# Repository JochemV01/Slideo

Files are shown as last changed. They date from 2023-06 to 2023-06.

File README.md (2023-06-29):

# Slideo
Welcome to this repository with the supplamentory materials of my final bachelor project. On this repo, you can find any relevant files you might need to reproduce the project or perform a follow-up.

## Contents
- CAD model
  - STL files which can be 3D printed
  - SolidWorks files which can be edited
- "Demoday" files
  (Demoday is the moment the project is presented to the public)
  - Arduino code (for demonstration purposes, a button activates the vibration patterns)
  - Electronics circuit which works with code
  - Poster (showcased on stand)
  - Video (showcased on stand and used in pitch)
- Questionnaire files
  - The full questionnaire with all questions
  - The responses to the questionnaire in Excel
- User test files
  - The video used
  - Arduino code (the haptic feedback synchronized with the video)
  - Electronics circuit which works with code
  - Results in Excel
- The design brief (initial goals and setting)
- An overview of the design sprint (brainstorming)
- The final report

## Contact
If you have any questions for me, feel free to reach out! You can reach me at j.r.p.verstegen@student.tue.nl.

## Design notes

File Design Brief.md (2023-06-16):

*Jochem Verstegen - 1561170 - FBP - Subject: AV Interaction*
# Design Brief
## Setting
There will be a transition period in which automated vehicles (AVs) will become more advanced and more common. A large part of this transition will consist of mixed traffic, which is a situation where humans manually driving a vehicle will share the roads with AVs. At first, AVs will not be fully automated yet, starting with level 3. But at some point, AVs can advance into fully automated vehicles capable of driving safely in any circumstances humans would be able to drive in. As AVs become increasingly more widespread, the opportunity to create an intelligent transport system (ITS) of sorts emerges, as this will lead to bigger advantages like increased safety, efficiency, sustainability and comfort (Ahangar et al., 2021).

This opportunity has already been identified by the EU, as is evident from their project called "[AutoNet2030](https://cordis.europa.eu/project/id/610542)", from 2013 to 2016. This project involved, amongst others, a definition of a network of AVs. As described by de La Fortelle et al. (2014): vehicles with a cooperative mode are either manually driven by a human while guided by the cooperation (*cooperative vehicle*), or support automated driving (*cooperative automated vehicle*). Cooperation should happen in local and global cooperative areas, where the local areas are meant for sharing manoeuvring information and the global areas are for communicating information like weather conditions or construction on a larger geographical area. Local cooperative areas can be either static or dynamic, the static area resides in infrastructure at strategic places like highway entrances or intersections, the dynamic area moves with a group of vehicles in short vicinity sharing similar traffic objectives. The goal of AutoNet is to allow cooperative vehicles to seamlessly create and join areas based on their positions relative to each other and infrastructure, it is a type of vehicle-to-everything (V2X) communication.

## Idea
My idea is to design a device, preferably physical with haptic interaction, which can be used on a bicycle. This device allows its user to become a part of the AutoNet network as described above, to understand it and interact in it. It can be used to actively participate in negotiations with other cooperative vehicles, mainly automated ones.

I will be focusing on a person driving a city bike, used as a means of personal transit from one location to another, on a route on which they are familiar. Using the device, the driver can indicate their plans, like what moves they are planning to make. The device will communicate this information with the network, in order to give the user feedback about whether its safe to make the move. This allows the user to take part in the complex communication within the system, and negotiate with it. A reason for aiming for haptic interaction is that it can be used with touch, decreasing the need to visually interact with the device. This way, the user does not have to shift their visual attention to the device and can continue monitoring their environment for safety. Additionally, it is a possibility to include multimodality in the design.

To have a clear goal for the design, it is important to determine a specific situation in which the design will be situated. This will be a major street with a speed limit of 50km/h, with a residential minor street on either side with a speed limit of 30km/h. The major street has painted bike lanes on either side, so cyclists are always on the right side of the street. The cyclist will be approaching these minor streets from the major street and wants to turn left into the left minor street. This would require crossing the street in order to complete the turn. The cyclist will use the device to indicate they are planning to make a left turn, using the feedback to determine if they can go or have to wait.

Some questions to be answered are:
- If the turn is not possible at the moment, how can this be made clear to the user?
- Is a system to communicate a human's intent desirable, or is it preferred to exclusively use eHMIs on other vehicles to tell the human where they can go?
	- Would people appreciate the extra control this gives them?
	- Would this change the amount of information to take into account when making a decision?
	- How would it affect trust levels?
- Would this only be helpful near the end of the transition period, or also earlier when AVs are not as common yet?
	- In case of a cooperative vehicle, which as described in AutoNet is not driving automatically, is communication more likely to happen through the network or from human to human?

Note that this device is not meant to replace eHMIs, but to coexist alongside it. Where eHMIs would be used to monitor the environment, this would be used to negotiate with the system.

## References
Ahangar, M. N., Ahmed, Q. Z., Khan, F. A., & Hafeez, M. (2021). A Survey of Autonomous Vehicles: Enabling Communication Technologies and Challenges. _Sensors_, _21_(3), Article 3. [https://doi.org/10.3390/s21030706](https://doi.org/10.3390/s21030706)

de La Fortelle, A., Qian, X., Diemer, S., Grégoire, J., Moutarde, F., Bonnabel, S., Marjovi, A., Martinoli, A., Llatser, I., Festag, A., & Sjöberg, K. (2014, September 8). _Network of automated vehicles: The AutoNet 2030 vision_. ITS World Congress. [https://hal-mines-paristech.archives-ouvertes.fr/hal-01063484](https://hal-mines-paristech.archives-ouvertes.fr/hal-01063484)

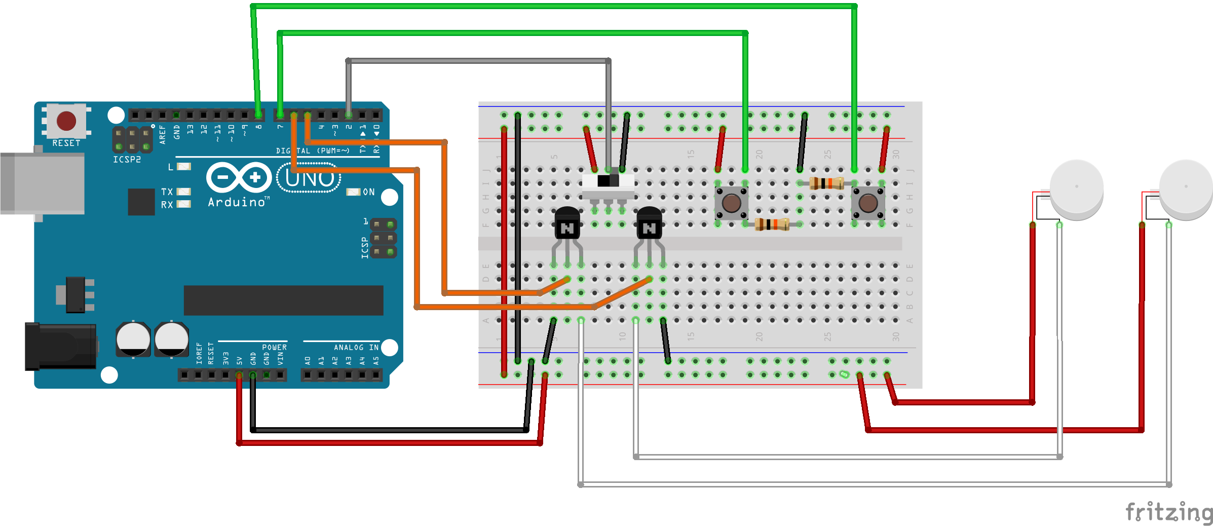
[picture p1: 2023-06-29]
Demoday/Electronics.png

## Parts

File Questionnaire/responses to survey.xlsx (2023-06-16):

ID | Starttime | Endtime | Language | Consent | first-thoughts-cyling-amongst-avs | cycling-experience | rate-current-infra | describe-current-infra | cycle-when-growing-up | rate-growup-infra | describe-growup-infra | sh-intuitive | sh-feel-safer | sh-trust-register-communicate | sh-feedback-behavior | sh-would-use | sh-like | sh-improve | sh-comments | rp-intuitive | rp-feel-safer | rp-trust-register-communicate | rp-feedback-behavior | rp-would-use | rp-like | rp-improve | rp-comments | ts-intuitive | ts-feel-safer | ts-trust-register-communicate | ts-feedback-behavior | ts-would-use | ts-like | ts-improve | ts-comments | kr-intuitive | kr-feel-safer | kr-trust-register-communicate | kr-feedback-behavior | kr-would-use | kr-like | kr-improve | kr-comments | compare-easiest-to-trigger | compare-likely-misfire | compare-best-feedback-reaction-avs | compare-right-amount-safety | compare-most-likely-use | compare-least-likely-use | age | reasons-to-cycle | statement-technology | toughts-cycling-with-concept
6 | 2023-03-24 10:57 | 2023-03-24 11:34 | en | yes | It's hard to envision how these cars will behave. If it is not consistent, I would constantly be watching the behaviour of these cars and trying to anticipate. However, humans are also not consistent, and to that I always anticipate by slowing down and watching for visual ques. | regularly | 8 | very good | yes different location | 6 | mediocre | 4 | 4 | 3 | 5 | 2 | Good reachability | / | / | 1 | 3 | 2 | 5 | 3 | Feels seamless | / | I move around a lot on my bike, I would be scared about accidentally triggering it | 1 | 2 | 5 | 2 | 1 | / | / | I would find this a really awkward interaction | 1 | 3 | 5 | 3 | 3 | / | / | I would find it disrupting for my knee placement whilst biking | sh; | sh;ts; | sh; | sh; | sh; | sh; | 25 | Traveling to work / school;Recreational;As a sport; | tech-useful-use-regularly
7 | 2023-03-24 11:29 | 2023-03-24 11:35 | en | yes | Bike can have eHMIs | regularly | 10 | very good | yes different location | 1 | pretty bad | 5 | 4 | 5 | 5 | 4 | No physical movement |  |  | 1 | 2 | 2 | 1 | 2 | Not practically feasible |  |  | 3 | 3 | 3 | 3 | 3 |  |  | Twisting seat is challenging when doing speed biking | 2 | 1 | 2 | 4 | 1 |  |  | It restricts my knee movements | sh; | rp; | sh; | sh; | sh; | rp; | 25 | Traveling to work / school;Recreational; | like-tech-enjoy-new
8 | 2023-03-25 12:15 | 2023-03-25 12:24 | en | yes |  | regularly | 10 | very good | yes same location |  |  | 2 | 4 | 3 | 4 | 4 |  |  | I would be scared to lose my balance when accidentally sliding the handle | 4 | 4 | 4 | 3 | 4 |  |  |  | 1 | 2 | 3 | 3 | 2 |  |  | I would again be scared to lose balance, and I don't know if I'm mobile enough to do this at every turn | 1 | 2 | 3 | 3 | 1 |  |  | I think it would be difficult to time this when cycling fast, which may result in hurting your knee | rp; | sh; | sh; | rp; | rp; | ts;kr;sh; | 20 | Traveling to work / school;Recreational; | like-tech-enjoy-new
9 | 2023-03-25 13:23 | 2023-03-25 13:47 | en | yes | As someone who commutes via bicycle, I feel that automated vehicles would lead to increased uncertainty. A lot of cyclists look to the drivers to see if they have been noticed, so something with the automated vehicles may have to replace this. Of course, a world of level 4 and 5 vehicle automation would be a very different one to that of ours today. | regularly | 9 | very good | no |  |  | 5 | 3 | 3 | 4 | 3 | I like that the interaction is simple to understand and straightforward. |  | I feel that the motion of sliding would decrease my trust in the handlebars, as I would be concerned about the risks of the handlebars moving when I expect them to be fixed. | 5 | 4 | 4 | 3 | 5 | I like that rp would not interfere with the normal operation of the bicycle, and that my hands would stay stationary. | perhaps some way to make sure the pedals can interface well with the user's shoes; not that friction is too low and the pedal rotates under their foot without it being clearly noticeable. |  | 5 | 2 | 2 | 4 | 2 | its operation would be simple and straightforward |  | I think that twisting the body while cycling could be potentially risky; like the handlebars, the seat is a contact point of the bicycle that riders rely on to be fixed. Rotating the body could potentially upset the user's balance- especially in situations where they want to signal a turn, expecting the seat to move, but it unexpectedly doesn't due to an unsafe situation. | 5 | 4 | 2 | 4 | 3 | I like that the idea is really unique and has a lot of potential. | I would be concerned about the system's ability to register my inputs reliably. Maybe some kind of haptic feedback could be implemented to show the user that they have activated the signal. The other major concern would be safety, like making sure the user doesn't get impaled in a crash, or that bailing in a crash (jumping off the bike) is not impeded. |  | kr;rp; | rp;ts; | kr; | kr;rp; | rp;kr; | sh;ts; | 23 | Traveling to work / school; | like-tech-enjoy-new
10 | 2023-03-25 13:24 | 2023-03-25 14:24 | en | yes | these vehicles have to see me and to be able to anticipate on me. For the rest it seems not any different from non-automated vehicles. | regularly | 8 | pretty good | yes same location |  |  | 1 | 1 | 3 | 2 | 1 | It is close to the hands on the handle bar and therefore ready to use | I would make it no sliding. Sliding means you have to pull, which causes you making a turn. Pulling with one hand also gets you out of balance, while balance is mandatory on a bike. | In the Netherlands only there are a lot of different handle bars, regular bikes, mountain bikes, racing bikes, "omafietsen" etc. The racing bike has a bar with various hand positions. where do you pull and how fast can you safely move your hands. | 4 | 4 | 1 | 1 | 4 | it is easy to use. When you want to make a turn you usually don't use the power of your feet so you can easily give signals. | only give feedback when the pedals are not powered because it maygive injuries | the signals need to transfer from the sensor to the computer. this needs to be done by a sliding connection because of the rotating pedal (near the foot). The pedal is near the road, and dirt and sand can easily cause wear to the connection, resulting in bad signals. | 4 | 2 | 2 | 5 | 2 | easy to do | make it vibrating | feedback may get you out of balance on the bike which can be dangerous | 4 | 1 | 5 | 5 | 1 | they are clear and present on your bike | Make sure they can be used at every pedal position | Unsafe during an emergency stop and they restrict the freedom of the legs and knees. | rp; | ts; | sh; | rp; | rp; | kr; | 47 | As a sport;shopping; | like-tech-enjoy-new | all these solutions reduce my biking skills and make me feel less confident on the bike. I would rather trust my own judging ability. Perhaps automated cars can learn body language of cylists.
11 | 2023-03-25 17:00 | 2023-03-25 17:08 | en | yes | I felt a bit scared to make a turn because I didnt dare to hold out my arms :( | regularly | 9 | pretty good | no |  |  | 2 | 3 | 2 | 2 | 1 |  |  |  | 4 | 4 | 3 | 4 | 3 | I think it is pretty innovative |  |  | 4 | 3 | 4 | 4 | 2 |  | I think it could be quite uncomfortable to use |  | 5 | 5 | 4 | 4 | 4 | It create a sense of security because it holds tight on my legs |  |  | kr; | ts; | kr; | kr; | kr; | ts; | 21 | Traveling to work / school; | tech-useful-use-regularly
12 | 2023-03-28 06:58 | 2023-03-28 07:08 | nl | yes | Nee nooit over nagedacht maar lijkt mij nest wel een oplossing voor diverse problemen | regularly | 8 | pretty good | yes same location |  |  | 4 | 4 | 4 | 4 | 4 | Dat je meer duidelijk kunt maken waar je na toe wilt gaan met beide handen aan het stuur | Geen idee |  | 3 | 2 | 2 | 2 | 2 | Lijkt mij niet zo veilig |  |  | 2 | 2 | 2 | 2 | 2 | Lijkt mij niet zo veilig |  |  | 2 | 2 | 2 | 2 | 2 | Lijkt mij niet zo veilig |  |  | sh; | rp;ts;kr; | sh; | sh; | sh; | kr;rp;ts; | 60 | Traveling to work / school; | tech-useful-use-regularly
13 | 2023-03-29 20:21 | 2023-03-29 20:29 | nl | yes |  | occasionally | 8 | very good | yes different location | 9 | very good | 1 | 1 | 1 | 1 | 3 |  |  |  | 1 | 1 | 2 | 1 | 1 |  |  |  | 1 | 1 | 2 | 1 | 1 |  |  |  | 1 | 1 | 1 | 2 | 2 |  |  |  | sh; | ts;rp;kr; | kr;sh; | sh; | sh; | ts;kr; | 37 | Traveling to work / school; | like-tech-enjoy-new | Ik zie het niet snel gebeuren
14 | 2023-03-29 22:00 | 2023-03-29 22:36 | nl | yes | Ik heb hier nog nooit over nagedacht, dus op dit moment heb ik nog geen gedachte hierover. | regularly | 7 | pretty good | yes same location |  |  | 3 | 3 | 2 | 3 | 4 | Je kan je handen aan het stuur houden. Dat is veiliger. | Geen idee, ik zou ze eerst moeten uitproberen om verbeteringen te kunnen aanbrengen. | Het uitschuiven voelt misschien beetje onnatuurlijk. | 4 | 4 | 3 | 3 | 4 | Je hoeft niet aan het stuur te trekken, wellicht veiliger en voelt vertrouwder | Pedalen misschien van kleur laten veranderen | Ik vraag me af of je nog prettig kan trappen met uitgebouwde pedalen | 4 | 3 | 3 | 2 | 4 | Dit lijkt me een kleine moeite om te doen. | Een soort van klik systeem aanbrengen, hoorbaar, zodat je hoort dat je voldoende gedraaid bent | Geen idee | 2 | 2 | 2 | 3 | 3 | Tja, hier heb ik beetje mijn twijfels over. Achteraf monteren is wellicht prettig en een goedkopere oplossing. | Iets erop verzinnen dat ze niet in de weg gaan zitten met het stallen van je fiets. | Mij lijkt het terug duwen van de staaf na de bocht niet zo prettig. | ts; | kr; | ts;sh;rp; | ts;rp; | ts;rp; | kr; | 52 | Traveling to work / school;Recreational; | like-tech-enjoy-new | Het lijkt me een hele uitdaging, zeker met meerdere zelfrijdende auto's om je heen.. Want hoe weet je dan dat alle zelfrijdende auto's jouw bedoeling gezien hebben?
15 | 2023-03-29 22:33 | 2023-03-29 22:43 | en | yes | We’re not there yet | regularly | 8 | very good | yes different location | 9 | very good | 1 | 1 | 1 | 1 | 1 | Don’t don’t don’t. Only useful if more than 99% use it. Including walking pedestrians, pets, etc. | Don’t. Solve the problem at the car end. | Don’t. | 1 | 1 | 1 | 1 | 1 | Don’t | Not use them | Don’t | 1 | 1 | 1 | 1 | 1 | Removal options | Don’t use them. If so, 100% reliability without ever changing batteries | Don’t | 1 | 1 | 1 | 1 | 1 | .. | Remove them | Horrible idea | sh; | ts; | sh;kr;ts; | sh; | sh; | sh; | 20 | Recreational; | like-tech-enjoy-new | I trust it about as well as I trust humans. Not enough to stake my life on them. I drive a smart car anyway and don’t mind looking away for a while. On the freeway
16 | 2023-03-30 09:14 | 2023-03-30 09:23 | nl | yes | Nederland is een fietsland. Ik ben benieuwd hoe een zelfrijdende auto al die fietsers in de gaten zou kunnen houden. | regularly | 6 | mediocre | yes different location | 6 | pretty good | 2 | 2 | 1 | 1 | 2 |  |  | Lijkt me, zeker voor oudere mensen die wat minder stabiel op een fiets zitten, niet veilig | 1 | 1 | 1 | 1 | 1 |  |  | Zeker niet veilig voor oudere fietsers op elektrische fietsen, bovendien moet je er maar net aan denken tijdens het fietsen | 1 | 1 | 1 | 1 | 1 |  |  | Ik vind dit persoonlijk een belachelijk idee. | 1 | 1 | 1 | 1 | 1 |  |  | Onzinnig idee, hoe verzin je het | ts; | kr; | sh; | ts; | sh; | ts;rp;kr; | 65 | Traveling to work / school;Recreational;Bezoek aan vrienden, boodschappen doen; | dont-mind-when-needed | Het lijkt mee helemaal niet veilig voor fietsers. Ze zijn toch al een kwetsbare groep weggebruikers, zelfrijdende auto’s vergroot die kwetsbaarheid alleen maar
17 | 2023-03-30 09:27 | 2023-03-30 09:38 | nl | yes | Eigenlijk nog geen gedachtes | regularly | 7 | pretty good | yes different location | 8 | very good | 3 | 2 | 2 | 2 | 3 | Ik kan me hier nog onvoldoende bij voorstellen | geen idee |  | 3 | 3 | 3 | 3 | 3 | Weet ik nog niet |  |  | 1 | 2 | 1 | 1 | 1 | niks |  | Als ik fiets ga ik wel eens verzitten omdat alsmaar dezelfde houding onprettig is. Dan zou ik met dit hulpmiddel regelmatig een verkeerd signaal afgeven aan achterliggers omdat ik mijn heupen dan even draai | 2 | 1 | 2 | 3 | 2 |  |  | Hoe gaat dit met opstappen? Ik heb een damesfiets met lage instap, en kan zeker niet mijn been over iets heen zwiepen. Ik zie dit echt niet voor me. | rp; | ts; | kr; | rp; | rp; | kr; | 52 | Traveling to work / school;boodschappen doen; | tech-useful-use-regularly
18 | 2023-03-30 09:34 | 2023-03-30 09:40 | nl | yes | Zal even wennen zijn, maar statistisch waarschijnlijk wel veiliger | rarely | 8 | very good | yes same location |  |  | 3 | 4 | 5 | 4 | 4 | Makkelijk te integreren | Zorgen dat ze zeker niet gaan schuiven als je over een hobbeltje gaat |  | 1 | 1 | 2 | 2 | 1 | Weinig | Niet aan beginnen, probeer maar eens met gedraaide voet een rondje te trappen als je niet hele sterke kruisbanden hebt |  | 3 | 2 | 2 | 3 | 3 | Makkelijk te bedienen | Zorgen dat het geen false positives geeft |  | 3 | 2 | 3 | 3 | 3 | Makkelijk te gebruiken | Geen idee |  | sh; | rp;ts; | sh;kr; | sh;kr; | sh; | rp;ts; | 30 | Recreational;Traveling to work / school; | tech-useful-use-regularly
19 | 2023-03-30 09:48 | 2023-03-30 09:57 | nl | yes | Ik fiets veel en vaak in Rotterdam en het grootste gevaar zijn niet auto's maar de overige fietsers/bromfietsers die denken dat de weg van hun is en ook vooral de voetgangers die met een telefoon aan hun oor of in hun hand totaal niet meer opletten als ze oversteken. | regularly | 9 | very good | yes different location | 8 | pretty good | 2 | 1 | 1 | 5 | 3 | Net veel | Geen idee |  | 1 | 1 | 1 | 1 | 1 |  |  |  | 1 | 1 | 1 | 1 | 1 |  |  |  | 1 | 1 | 1 | 1 | 1 |  |  |  | rp; | ts;kr;sh; | rp; | rp; | rp; | ts;sh;kr; | 61 | Traveling to work / school;Recreational; | like-tech-enjoy-new | Ik vertrouw het meest op mezelf. Daarna auto's met een bestuurder erin en past als laatste een zelf rijdende auto. En daarbij hoe kan ik een zelf rijdende auto (of een auto met bestuurder die zelf rijdt) herkennen. Nogmaals ik vertrouw mezelf het meest. En over de enquete: voeg ook een optie toe : geen van de 4 want nu moest ik een antwoord geven wat ik eigenlijk niet wilde.
20 | 2023-03-30 09:25 | 2023-03-30 10:06 | nl | yes | Je kan als fietser ook niet zien of een zelfrijdende auto jou wel heeft gezien. Bij een bestuurder kan je dat wel zien. Waarom zou je de problematiek dat een zelfrijdende auto een fietser niet goed kan inschatten verschuiven naar de fietser? Het lijkt mij dat een zelfrijdende auto zich moet aanpassen aan de andere verkeersdeelnemers en niet dat de andere verkeersdeelnemers zich moeten aanpassen aan zelfrijdende auto's. | regularly | 8 | pretty good | yes different location | 5 | pretty bad | 1 | 1 | 1 | 4 | 2 |  |  | Ik begrijp niet goed hoe je kan voorkomen dat er een bedoeling wordt geregistreerd zonder dat jij het wil (omdat je per ongeluk iets verschuift.). Hoe weet de fiets dat je de bocht volledig hebt afgerond en nu weer rechtdoor gaat fietsen? | 1 | 1 | 1 | 4 | 1 |  |  | Ik begrijp niet goed hoe je kan voorkomen dat er een bedoeling wordt geregistreerd zonder dat jij het wil (omdat je per ongeluk iets verdraait.). Hoe goed blijft dit draaien als de trappers onder de modder zitten? Hoe weet de fiets dat je de bocht volledig hebt afgerond en nu weer rechtdoor gaat fietsen? | 1 | 1 | 1 | 4 | 2 |  |  | Ik begrijp niet goed hoe je kan voorkomen dat er een bedoeling wordt geregistreerd zonder dat jij het wil (omdat je per ongeluk iets verdraait.). Hoe weet de fiets dat je de bocht volledig hebt afgerond en nu weer rechtdoor gaat fietsen? | 1 | 1 | 1 | 4 | 1 |  |  | Het ziet eruit alsof je tijdens het fietsen continu staven tegen je knieën krijgt. Lijkt me ook lastig voor fietsen zonder stang, waarbij de gebruikers niet gewend zijn dat er staven zitten die hun verhinderen makkelijk op en af te stappen. Hoe weet de fiets dat je de bocht volledig hebt afgerond en nu weer rechtdoor gaat fietsen? | ts;sh;rp; | sh;rp;ts; | sh; | sh; | rp; | kr;sh;ts; | 47 | Recreational;Boodschappen; | like-tech-enjoy-new | Het lijkt mij een slecht idee. Als je al wil dat fietsers afslaan beter kunnen communiceren dan lijkt het logischer dat er met knipperlichten wordt gewerkt. Net zoals op een brommer/scooter, inclusief de manier om het knipperlicht te activeren. Dan kan je "onder water" natuurlijk tegelijkeen ander signaal sturen naar zelfrijdende auto's.
21 | 2023-03-30 10:47 | 2023-03-30 10:55 | nl | yes |  | occasionally | 8 | pretty good | yes different location | 6 | mediocre | 1 | 1 | 2 | 2 | 1 | Niets | Niet laten schuiven | Schuiven zal snel tot een onbedoelde richtingsverandering leiden en is daarmee onveilig. | 2 | 2 | 2 | 3 | 1 | Geen handen nodig, beïnvloedt stuurgedrag niet. | Geen idee | Conflicteert met click-pedalen, die ook al een draaiende beweging gebruiken bij het ontgrendelen. | 1 | 1 | 1 | 1 | 1 | Beïnvloedt de balans op de fiets en daarmee het stuurgedrag. | Niet invoeren. | Lijkt me erg ongemakkelijk. | 2 | 2 | 2 | 2 | 1 | Houdt handen vrij. | Geen idee | Bemoeilijkt op- en afstappen. Onveilig. | rp; | ts;kr; | rp; | rp; | rp; | ts;sh; | 53 | Recreational;As a sport; | tech-useful-use-regularly
22 | 2023-03-30 10:39 | 2023-03-30 10:55 | nl | yes | Ik ga ervan uit dat zodra dit de realiteit is, er voldoende onderzoek is gedaan om er zeker van te zijn dat het veilig kan. Misschien is het tegen die tijd wel veiliger dan wanneer er een onvoorspelbare automobilist rijdt. | regularly | 8 | very good | yes same location |  |  | 3 | 4 | 3 | 4 | 4 |  | Ik zou misschien iets willen dat wat meer opvalt, zodat andere fietsers ook beter zien wat ik ga doen. |  | 4 | 4 | 3 | 3 | 4 | Makkelijk te gebruiken met handen aan het stuur | Ik weet niet of je de feedback van de pedalen (bv trillingen) goed kunt waarnemen op slechte/hobbelige wegen bijvoorbeeld. |  | 2 | 3 | 3 | 3 | 3 |  | Ik denk dat het moeilijker te gebruiken is dan de andere opties, met name voor ouderen. |  | 3 | 4 | 4 | 4 | 4 | Zijn wat groter en degelijker om te gebruiken dan de rest denk ik | Is denk ik wel oncomfortabel met op en afstappen |  | sh;kr; | ts;rp; | kr;sh; | kr; | sh;kr; | ts; | 20 | Traveling to work / school;As a sport; | tech-useful-use-regularly
23 | 2023-03-30 10:09 | 2023-03-30 10:58 | nl | yes | Ik zou constant op mijn hoede zijn, omdat ik voorlopig weinig vertrouwen heb in de zelfrijdende technologie. | regularly | 7 | pretty good | yes different location | 7 | pretty good | 1 | 1 | 1 | 1 | 2 | Niets | Slecht idee, verbeteren is zinloos. | Uitschuivende handvatten (let op: met dubbel t!) maken een onnatuurlijke beweging noodzakelijk en geven kans op slingeren. Veel fietsen hebben handvatten die niet min of meer naar links/rechts wijzen, maar naar achteren. | 1 | 1 | 1 | 1 | 1 | Niets | Slecht idee, verbeteren zinloos. | Bezwaren vergelijkbaar met de handvatten. De kans op onbedoeld richting aangeven lijkt me ook nog eens groot, vooral bij fietsen in druk stadsverkeer. | 1 | 1 | 1 | 1 | 1 | Niets. | Het mechanisme vastzetten! | Een draaiend zadel? Echt waar? Heeft u wel eens gefiets met een zadel dat wat kon bewegen? En wat doet dit high-tech zadel als ik bij een kruising links over mijn schouder kijk om te zien of ik veilig rechtdoor kan? | 1 | 1 | 1 | 1 | 1 | Niets | Onmogelijk te verbeteren. | Dit is het meest onpraktische en gevaarlijkste scenario van dit onderzoek, bv bij opstappen, afstappen, voet op de grond (bv bij stoplicht). De kans op (eenzijdige) ongelukjes, valpartijen en slingeren is veel te groot. | kr;ts;rp; | ts;kr;rp; | sh; | sh;rp;ts; | sh; | ts;rp;kr; | 56 | Traveling to work / school;Recreational; | like-tech-enjoy-new | Als zelfrijdende auto's niet goed kunnen reageren op fietsers, is de technologie kennelijk niet goed genoeg. De vier scenario's vind ik ronduit slecht en vergezocht. Het zijn onnatuurlijke "oplossingen" voor andermans problemen. Als "richtingaanwijzer" op een fiets lijkt me een (terugverende) druk- of schuifknop in beide handvatten, onder of naast de duim, nogal voor de hand te liggen en verreweg het handigst te gebruiken. Waarom wordt dat niet meegenomen in het onderzoek? Niet aan gedacht of niet sexy genoeg? Bij de laatste vragen (de keuze voor een scenario) heb ik lukraak wat ingevuld: *geen enkel scenario* wil ik gebruiken of verhoogt mijn veiligheids gevoel.
24 | 2023-03-30 11:27 | 2023-03-30 11:42 | nl | yes | Zoals het "besturen" van een semi-zelfrijdende auto is het een kwestie van vertrouwen in de hulpmiddelen, eerst zweet op het voorhoofd van de spanning later relaxed achteroverleunend | occasionally | 8 | pretty good | yes same location |  |  | 1 | 2 | 2 | 3 | 2 | Ik zie alleen maar nadelen | voorkomen dat er per ongeluk geschoven wordt | te fragile in mijn ogen | 1 | 1 | 1 | 1 | 1 | niets enkel ongemak | niet te verbeteren wederom te snel verkeerd te gebruiken | niets | 1 | 1 | 1 | 1 | 1 | niets | onmogelijk | comfort is helemaal weg op deze manier | 1 | 1 | 1 | 1 | 1 | niets | ?? | levensgevaarlijk | rp;ts; | ts;sh;rp; | kr; | ts; | ts; | kr;ts;sh; | 54 | Traveling to work / school; | like-tech-enjoy-new
25 | 2023-03-30 11:25 | 2023-03-30 11:48 | nl | yes | Erg gevaarlijk. Als er echt zelf rijdende auto's dan stop ik met fietsen | occasionally | 8 | mediocre | no |  |  | 1 | 1 | 1 | 1 | 1 | Dit probleem moet opgelost worden door de bestuurder of eigenaar van die auto, niet door de fietser |  | Een automobilist hoeft zich niets aan te trekken van een of ander verzinsel van iemand. Wat ook niet gaat werken is dat het jullie kennelijk niet bekend is dat de meeste sturen van een fiets niet naar rechts en links uitsteken naar achter, Zoals een stuur van een stadsfiets. En wat denk ja van een vlinderstuur op een wielrennersfiets. Zaterdag is het 1 APRIL. Leuk bedachte grap | 1 | 1 | 1 | 1 | 1 | niets | gaat niet | De voet op de trapper op de tekening staat n helemaal verkeerd. Een trapper zit tegen de kan aan, niet onder de voorvoet | 1 | 1 | 1 | 1 | 1 | het idee alleen al. NEE | vast zetten |  | 1 | 1 | 1 | 1 | 1 | niets | niet invoeren | bestuurders van bestuurder loze autoś uitleggen dat er ook fietsers op de weg rijden, en dat een fietser nu eenmaal geen verplicht fietsrijbewijs heeft | rp; | sh; | rp; | sh; | kr; | kr;sh;ts; | 64 | goedkoper als auto; | not-interested | De bestuurders van bestuurderloze auto's veroorzaken een probleem, dus daar moet het opgelost worden, niet bij de fietser
26 | 2023-03-30 15:34 | 2023-03-30 15:48 | nl | yes |  | regularly | 8 | very good | yes different location | 7 | pretty good | 1 | 1 | 1 | 1 | 1 |  |  | Door het verschuiven van de handvatten verander je ook je rijeigenschap en het "gevoel" met je fiets. | 1 | 1 | 1 | 1 | 1 |  |  | Bij het fietsen op een racefiets op mtb (door de stad) zit je vast aan je pedalen daar door geen mogeijkheid om de hak te kunnen draaien. | 1 | 1 | 1 | 1 | 1 |  |  | Door het gemak van het draaien draai je makkelijk weer terug in de originele positie of zelfs de verkeerde richting op. Vergelijkbaar met een verouderde verende zadelpen die ook makkelijk zijdelings beweegt. | 2 | 3 | 1 | 1 | 1 |  |  | Het gevoel van vrijheid raak je denk ik kwijt door de staven aan je knieën te bevestigen. Hoe om te gaan met extreme O benen of mensen die van zichzelf met "zwenkende" knieën fietsen? | rp;sh; | ts;rp; | kr; | sh; | sh; | ts;kr;rp; | 35 | Traveling to work / school;Recreational;As a sport; | like-tech-enjoy-new
29 | 2023-03-30 16:08 | 2023-03-30 16:18 | en | yes | As I cyclist it shouldn't matter tome whether the vehicles around me are automated or not. | regularly | 9 | very good | yes different location | 6 | mediocre | 1 | 1 | 1 | 1 | 1 | Nothing | Forbid them. | If I have to pull a handle sideways, I can't at the same time indicate my direction change the normal way to every other traffic participant that is not an automated vehicle. | 2 | 3 | 2 | 2 | 2 |  |  |  | 2 | 2 | 3 | 2 | 2 |  |  |  | 2 | 2 | 2 | 2 | 2 |  |  |  | sh; | sh; | sh; | rp; | rp; | sh; | 45 | Traveling to work / school; | like-tech-enjoy-new
30 | 2023-03-30 18:06 | 2023-03-30 18:40 | nl | yes | In eerste instantie lijkt het mij heel gevaarlijk omdat fietsers en dan met name kinderen en ouderen vaak heel onverhoeds bewegingen kunnen maken... | regularly | 7 | pretty good | yes same location |  |  | 1 | 1 | 1 | 1 | 1 |  | Het lijkt mij erg gevaarlijk | Het lijkt mij erg gevaarlijk omdat ik niet kan inschatten wat er gebeurd bij onverwachte bewegingen. Hoe kun je het stuur stevig vasthouden terwijl de handgrepen uittrekbaar zijn. Verder zouden de extra lichten mij extra afleiden van het verkeer. En dat is in strijd met het veilig willen fietsen | 3 | 3 | 3 | 2 | 4 | Je blijft je stuur goed vasthouden |  | Zou dit dan zijn zodat je je hand niet meer uit steekt? Hoe zien andere weggebruikers wat jij gaat doen in het verkeer? Hoe zit het met pedalen met kliksysteem? | 2 | 1 | 2 | 3 | 1 |  |  | Dit lijkt mij persoonlijk ook heel gevaarlijk omdat ik door de draaiende beweging te maken me niet stabiel zou voelen. En dus onveilig. Zal een groot verschil geven of je jong of oud bent, of je lichamelijk gezond bent of niet | 4 | 4 | 4 | 3 | 2 | Je blijft stabieler |  | Deze manier lijkt mij het minst ingrijpende qua fietsen en stabiliteit. Maar vraag me af of dit bruikbaar is wanneer je knieklachten hebt. Verergeren deze dan omdat je een onnatuurlijke beweging moet doen bij het fietsen? | kr; | sh;ts;rp; | rp;kr; | kr; | kr; | ts;sh; | 51 | Recreational; | dont-mind-when-needed | Ik vind eigenlijk alle opties niet toe te passen voor mij, lichamelijk gezien. Ikzelf zou eerder een mogelijkheid uitzoeken zoals een knopje op de linker en rechter stuurhelft om te activeren. Net zoals bv de versnelling te verzetten. Zo blijft mijn aandacht bij het verkeer, en ik blijf stabiel op mijn fiets
31 | 2023-03-31 07:48 | 2023-03-31 07:54 | nl | yes |  | regularly | 8 | very good | yes different location | 8 | very good | 1 | 1 | 1 | 1 | 1 |  |  |  | 1 | 1 | 1 | 1 | 1 |  |  |  | 1 | 1 | 1 | 1 | 1 |  |  |  | 1 | 1 | 1 | 1 | 1 |  |  |  | ts; | sh;rp;ts; | kr; | rp; | rp; | sh;kr;rp; | 60 | Traveling to work / school; | tech-useful-use-regularly
32 | 2023-03-31 09:52 | 2023-03-31 13:18 | nl | yes | Nee, ik heb daar nog nooit over nagedacht. | regularly | 8 | very good | yes different location | 8 | very good | 3 | 4 | 2 | 3 | 4 | Het lijkt me dat je eerder uit balans raakt. | Door inknijpen van het handvat een binnendeel naar buiten schuift en weer terug, minder kans op uit balans raken en uitschuifbare deel kan langer zijn dan alleen een schuifbaar handvat. | Ik ben bang dat het uitschuiven ook kan gebeuren als het niet nodig is, daardoor is de kans dat de fietser uit balans raakt te groot. | 2 | 2 | 2 | 2 | 2 | Als de pedalen een sein geven aan de zelfsturende auto's zal daar vast op gereageerd worden. Het lijkt met voor niet-zelfrijdende auto's, dus met gewoon een chauffeur lastig om zo alles onder controle te houden. | geen idee | Nee, nooit over nagedacht. | 1 | 1 | 2 | 3 | 1 | Ik vind een draaiend zadel helemaal niets! | Vastzetten! | Ik vind een draaiend zadel erg onstabiel. | 3 | 3 | 3 | 3 | 3 | Je hoeft je handen niet te gebruiken. | Ik heb geen idee, maar is er ook nagedacht over een kinderzitje aan het stuur? Ik zie die combinatie niet zo goed voor ogen. Volgens mij past dat niet beide tegelijk op een fiets. | nee | sh; | ts;kr;rp; | sh; | sh; | sh; | kr;ts;rp; | 66 | Recreational;boodschappen doen; | tech-useful-use-regularly | Het geeft me geen veilig gevoel. De mens is wispelturig, kijkt om zich heen, bedenkt op het laatste moment dat er een andere richting gevolgd moet worden. Ik ben bang dat zelfsturende auto's niet op tijd zullen reageren.
33 | 2023-04-11 14:50 | 2023-04-11 14:55 | en | yes |  | occasionally | 8 | very good | yes different location | 6 | pretty good | 1 | 1 | 2 | 2 | 2 |  |  |  | 1 | 1 | 1 | 1 | 1 |  |  |  | 1 | 1 | 1 | 1 | 1 |  |  |  | 1 | 1 | 1 | 1 | 1 |  |  |  | sh; | ts;rp;sh; | sh; | sh; | sh; | kr;ts;rp; | 35 | Recreational; | like-tech-enjoy-new
34 | 2023-04-12 09:06 | 2023-04-12 09:24 | nl | yes | De eerste gedachte is dat ik als fietser niet iets extras moet aanschaffen om veilig in het verkeer te kunnen navigeren. De zelfrijdende auto is dan niet op een hoog genoeg niveau om echt zelfrijdend te zijn. | occasionally | 9 | pretty good | yes different location | 9 | very good | 2 | 2 | 4 | 3 | 2 | De mogelijkheid voor knipperlichten voor overige weggebruikers ( die wel nodig zijn omdat anders voetgangers en fietsers niet weten wat de bedoeling van de fietser is) | ik zou het eerder een knop maken die kan schuiven ipv de handvaten zelf. | het idee van het schuiven van de handvaten geeft een idee van een mogelijke onbalans omdat je een handvat moet schuiven. | 4 | 2 | 3 | 4 | 2 | Concept is simpel, je kan je handen aan het stuur houden. |  |  | 1 | 1 | 4 | 3 | 2 | Het zal een duidelijk makkelijk te interpreteren signaal zijn |  | Als fietser lijkt mij niks ververlender dan een zadel wat kan draaien. Als je kracht wil zetten tijdens het fietsen komt er vaak ook kracht op het zadel waardoor het vaak onbedoeld zal draaien. | 1 | 2 | 4 | 4 | 3 | Duidelijk te interpreteren signaal |  | Ik ben groot en lang, de kniestaven zullen dus makelijk aanpasbaar moeten worden wil je mij bv op die fiets kunnen laten fietsen. Ik pak soms ook wel de fiets van mijn vrouw die 30 cm kleiner is, dus grote aanpasbaarheid nodig. | sh; | kr;ts; | sh;kr; | rp;sh; | sh; | kr;ts; | 44 | Recreational;As a sport; | like-tech-enjoy-new | Van je vier concepten lijkt mij de handvaten het handigst maar dan aangepast als een simpele aangepaste knop ipv het onthandige uitschuiven. Belangrijkste is dat het concept niet alleen de autos in gedachten houd maar ook het communiceren naar andere fietsers, wandelaars en ook bv de stoplichten.
 |  | 0.7
age | sh-intuitive | sh-feel-safer | sh-trust-register-communicate | sh-feedback-behavior | sh-would-use | Jitter intuitive | Jitter safer | Jitter trust | Jitter feedback | Jitter would use
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

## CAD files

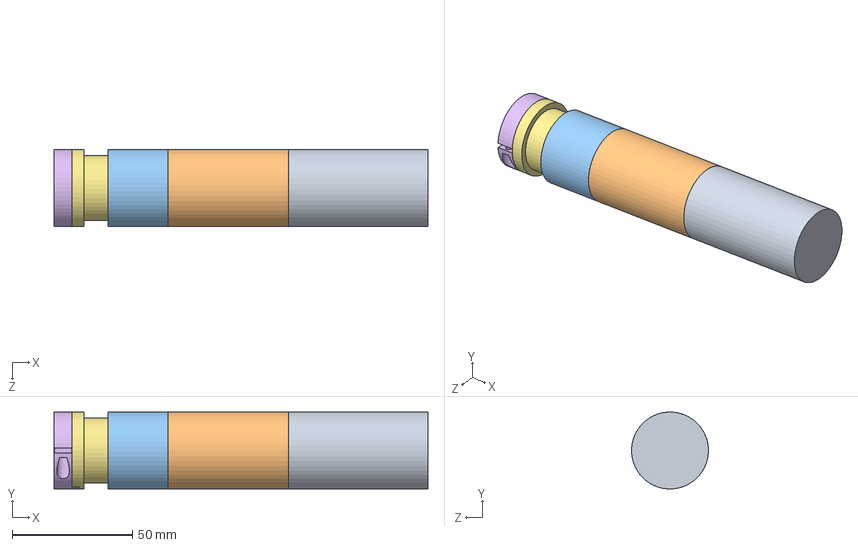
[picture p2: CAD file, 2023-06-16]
CAD-model/SolidWorks-files/Complete slidable handle.SLDASM
155.5 x 32.0 x 32.0 mm
Inner part inside
ODI Clamp
Inner part middle
Inner part outside
outer part inside
outer part middle
outer part outside

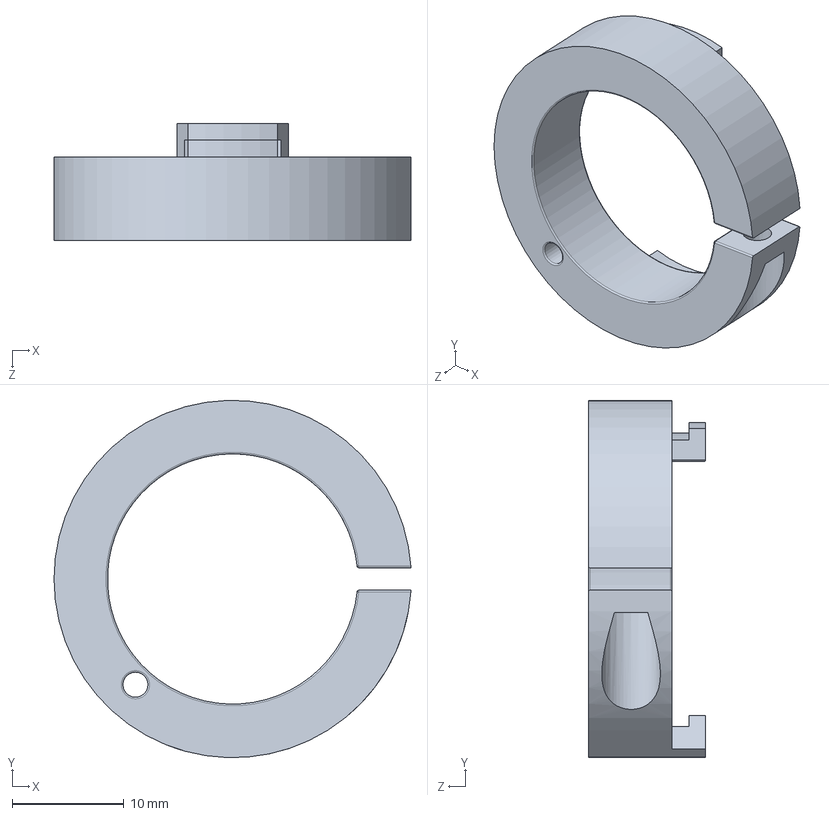
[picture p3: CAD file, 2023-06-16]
CAD-model/SolidWorks-files/ODI Clamp.SLDPRT
32.0 x 32.0 x 10.5 mm

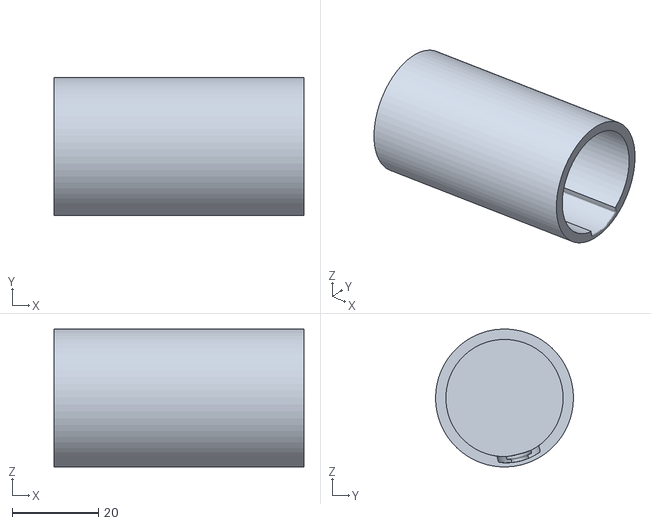
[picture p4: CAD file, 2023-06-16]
CAD-model/STL-files/outer outside - white plastic - 2x.STL
58.0 x 32.0 x 32.0

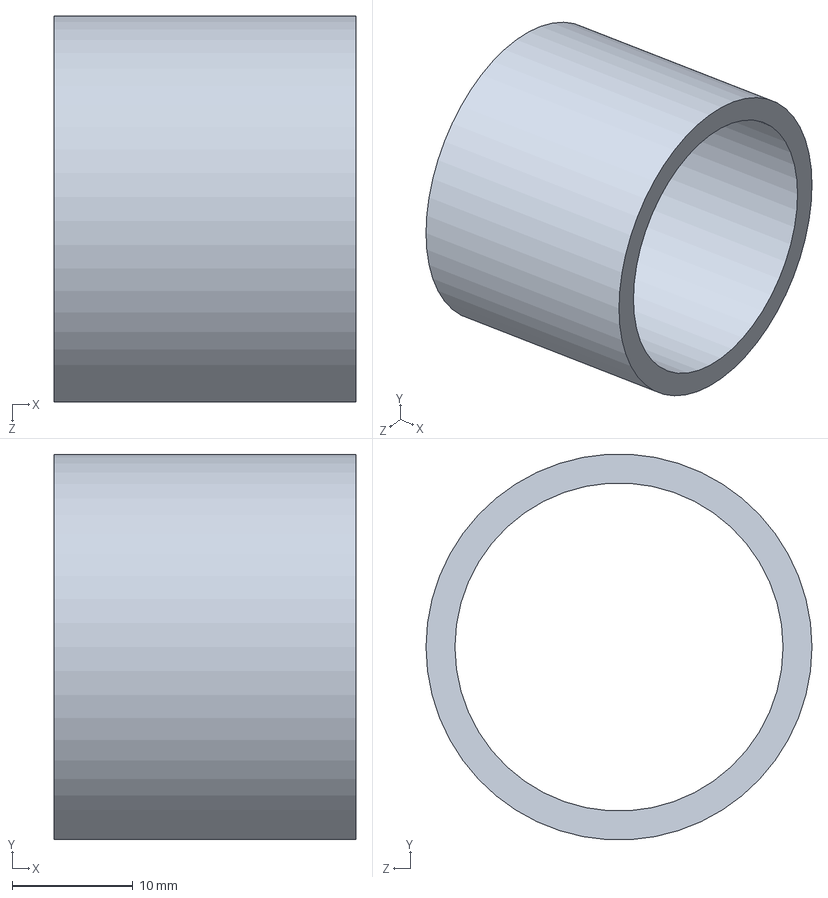
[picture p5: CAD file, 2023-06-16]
CAD-model/SolidWorks-files/outer part inside.SLDPRT
25.0 x 31.9 x 32.0 mm

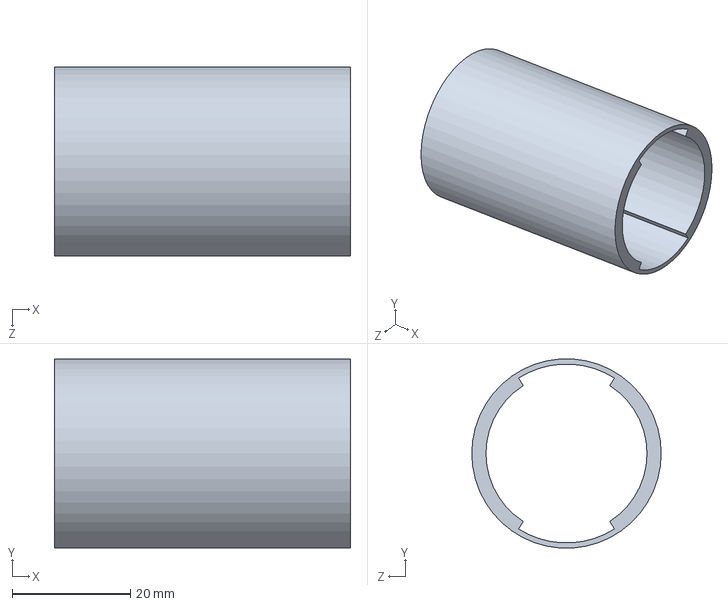
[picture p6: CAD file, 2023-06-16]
CAD-model/SolidWorks-files/outer part middle.SLDPRT
50.0 x 31.9 x 32.0 mm

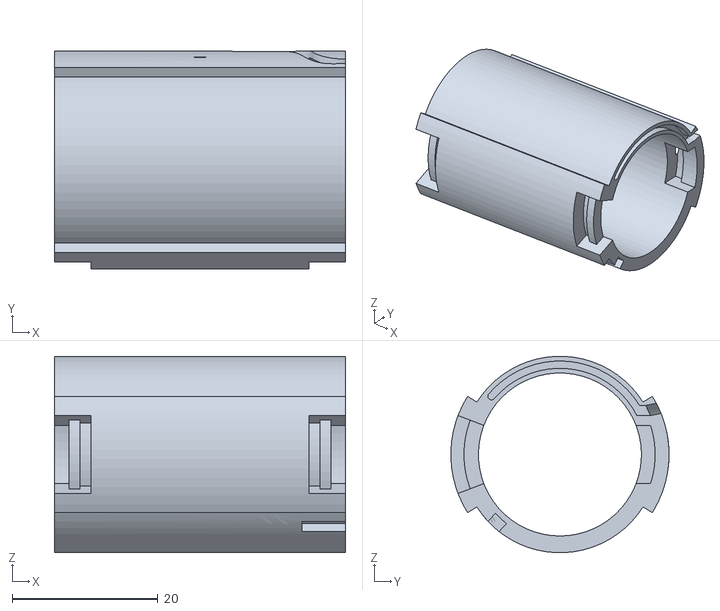
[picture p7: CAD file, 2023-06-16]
CAD-model/STL-files/inner middle - white plastic - 2x.STL
40.0 x 30.0 x 27.0

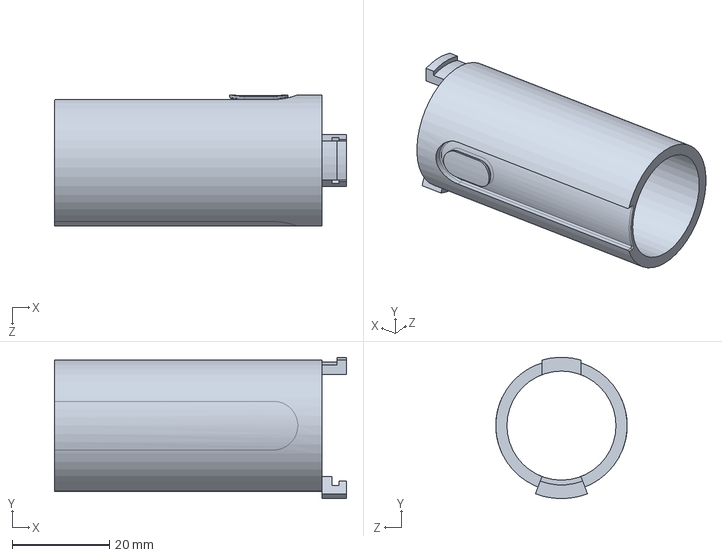
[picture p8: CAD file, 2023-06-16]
CAD-model/SolidWorks-files/Inner part outside.SLDPRT
60.0 x 29.0 x 27.0 mm

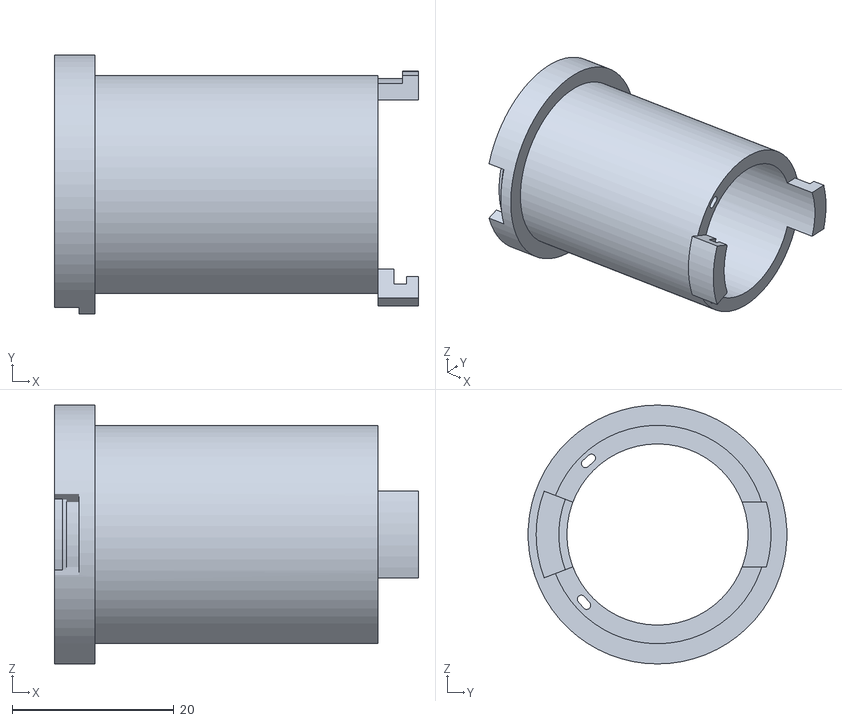
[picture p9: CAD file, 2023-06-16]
CAD-model/STL-files/inner inside - white plastic - 2x.STL
45.0 x 32.0 x 32.0

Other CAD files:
CAD-model/STL-files/outer inside - white plastic - 2x.STL
CAD-model/SolidWorks-files/outer part outside.SLDPRT
CAD-model/STL-files/outer middle - white plastic - 2x.STL
CAD-model/SolidWorks-files/Inner part middle.SLDPRT
CAD-model/STL-files/clamp - white plastic - 2x.STL
CAD-model/STL-files/inner outside - white plastic - 2x.STL
CAD-model/SolidWorks-files/Inner part inside.SLDPRT

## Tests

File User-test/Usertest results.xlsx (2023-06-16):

ID | Which try included communication? | Mean with communication | Mean without communication | What do you think the vibrations mean? | How effective were the vibration patterns in providing feedback? | How well did the vibration patterns help you understand your environment? | How comfortable did the vibration patterns feel? | How easy to understand were the vibration patterns? | How natural do the vibrations feel? | Overall, how satisfied are you about this user feedback? | Do you need additional explanation in order to understand the vibration patterns fully? | What do you think the vibrations mean?2 | How effective were the vibration patterns in providing feedback?2 | How well did the vibration patterns help you understand your environment?2 | How comfortable did the vibration patterns feel?2 | How easy to understand were the vibration patterns?2 | How natural do the vibrations feel?2 | Overall, how satisfied are you about this user feedback?2 | Do you need additional explanation in order to understand the vibration patterns fully?2
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

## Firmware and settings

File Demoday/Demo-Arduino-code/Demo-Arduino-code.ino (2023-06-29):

/* June 2023
 * Code by Jochem Verstegen for Final Bachelor Project
 * Eindhoven University of Technology, faculty of Industrial Design
 *
 * This code can be used to demonstrate the haptic feedback.
 * The left button activates the left vibration motor, the right button the right motor.
 * Technically, it is possible for both buttons to trigger both motors.
 * For the electronics needed, please see the "Electronics.png" file in the demoday folder.
 * Note the presence of a switch connected to pin 2.
 * This switch can toggle between the regular mode and navigation mode.
 * When this switch is not included, it will default to the regular mode.
 *
 * The regular mode contains the feedback when indicating a turn (in this case pressing a button).
 * The navigation mode indicates upcoming turns when following turn-by-turn nagivation.
 */

const int ledPin = 13;
const int vibrPinL = 6;
const int vibrPinR = 5;
const int buttonPinL = 7;
const int buttonPinR = 8;
const int modePin = 2;

String side = "none";
int sideNr = 0;

float intensity;
const int max_intensity = 208; // set the max PWM rate for the max voltage. Max 4V = 0.8 * 255 = 204.
const int min_intensity = 25; // set the min PWM rate at which the motors still vibrate. Trial and error.

long int time = 0;
long int vibrateTime = 0;
bool vibrating = false;
int step = 0;
int order = 0;
int count = 0;
int randomCount = 0;

void setup() {
  pinMode(vibrPinR, OUTPUT);
  pinMode(vibrPinL, OUTPUT);
  pinMode(ledPin, OUTPUT);
  pinMode(buttonPinL, INPUT);
  pinMode(buttonPinR, INPUT);
  pinMode(modePin, INPUT);
}

/* Two "modes" needed: Free turning (feedback) and navigation
### Free turning:
User can determine when to turn. Before the turn, they indicate their intention.
This will be communicated to the AVs around the user, and feedback will be given
to the user through vibrations. Blinkers can activate too, but not in this prototype.
________________________________

- Before turn, user pulls handle
- Handle vibrates a few times as comfirmation (2 quick short vibrations?)
- (Optional: Vibrate to indicate safety to take turn)
  - Waiting: Keep vibrating both weak
  - Safe to go: Vibrate side stronger

### Navigation:
User can set a destination, or a full route. Each turn will be communicated to the
user using vibrations. User can confirm a turn, which will make the vibrations less
frequent / intense.
________________________________

- Long before turn, indicate turn with a couple short vibrations
- After, indicate using less vibrations, but longer and stronger
- Right before turning, confirm again with 2 strong vibrations (long - short)
- When comfirmed by user, perhaps only do final alert (still confirm intention)
*/

void loop() {
  if (digitalRead(modePin) == HIGH) navigationMode();
  else turningMode();
}

void turningMode() {
  // this mode is the regular usage mode, to indicate a turn:
  switch (order) {
    case 0: // Checking for user action:
      if (buttonState() != "none") {          //when handle is slided out:
        side = buttonState();                   //register which side it was,
        order = 1;                              //go to next step,
        time = millis();                        //and already start timer.
      }
      break;
    case 1: // Confirmation of user action:
      if (millis() >= time + 400) {           //THEN after 500ms do this:
        vibrateOnce(side, 75, 300);             //similar short vibration,
        if (!vibrating) {
          order = 2;                            //and go to next step.
          time = millis();
          randomCount = random(4,8);
          delay(500);
        }
      } else {                                //FIRST do this:
        vibrateOnce(side, 75, 300);             //short vibration.
        if (!vibrating) delay(100);
      }
      break;
    case 2: // Waiting during communication:
      if (millis() >= time + 400) {               //THEN after 400ms do this:
        vibrateCurve("both", 15, 1, 400, 400);     //gradually go down,
        if(!vibrating) {                            //IF finished vibrating,
          time = millis();                            //set time so it will vibrate up again,
          count++;
          if (count >= randomCount) {                 //and after a few times, move to next step
            order = 3;
            count = 0;
            delay(200);
          }
        }
      } else {
        vibrateCurve("both", 1, 15, 400, 0);     //FIRST gradually go up.
      }
      break;
    case 3: // Confirm safe to go:
      vibrateOnce(side, 70, 200);
      while (vibrating) vibrateOnce(side, 60, 200);
      delay(100);
      vibrateOnce(side, 100, 600);
      while (vibrating) vibrateOnce(side, 100, 500);
      order = 0;
      break;
  }
}

void navigationMode() {
  // this mode will navigate the user around, using haptic feedback:
  switch (order) {
    case 0: // Wait random amount until next turn:
      delay(random(3000,5000));
      sideNr = random(1,3);
      Serial.println(sideNr);
      if (sideNr == 1) side = "left";
      else side = "right";
      order = 1;
      break;
    case 1: // First alert of upcoming turn:
      for (int i = 0; i < 4; i++) {
        vibrateOnce(side, 30, 100);
        while(vibrating) vibrateOnce(side, 30, 100);
        delay(100);
      }
      order = 2;
      delay(3000);
      break;
    case 2: // Second alert of upcoming turn:
      for (int i = 0; i < 3; i++) {
        vibrateOnce(side, 50, 200);
        while(vibrating) vibrateOnce(side, 50, 200);
        delay(200);
      }
      order = 3;
      delay(2000);
      break;
    case 3: // Confirm safe to go:
      vibrateCurve(side, 1, 80, 400, 200);
      while (vibrating) vibrateCurve(side, 1, 80, 400, 200);
      delay(200);
      vibrateOnce(side, 100, 200);
      while (vibrating) vibrateOnce(side, 100, 200);
      order = 0;
      break;
  }
}

String buttonState() {
  String result;
  int leftButton = digitalRead(buttonPinL);
  int rightButton = digitalRead(buttonPinR);
  if (leftButton == HIGH && rightButton == LOW) result = "left";
  else if (leftButton == LOW && rightButton == HIGH) result = "right";
  else if (leftButton == HIGH && rightButton == HIGH) result = "both";
  else result = "none";
  return result;
}

void vibrateOnce(String direction, int strength, int duration) {
  if (!vibrating) {
    vibrating = true;
    setVibrate(direction, strength);
    digitalWrite(ledPin, HIGH);
    vibrateTime = millis();
  }
  if (millis() >= vibrateTime + duration) {
    setVibrate(direction, 0);
    digitalWrite(ledPin, LOW);
    vibrating = false;
    step = 0;
  }
}

void vibrateCurve(String direction, int startStrength, int endStrength, int duration, int timeAfter) {
  float stepDuration = 10;
  float stepSize = (endStrength - startStrength) / (duration / stepDuration);
  float strength;
  if (millis() >= vibrateTime + stepDuration) {
    if (step < duration / stepDuration) vibrateTime = millis();
    strength = startStrength + stepSize * step;
    if (vibrating) setVibrate(direction, strength);
    if (step == 0) {
      vibrating = true;
      digitalWrite(ledPin, HIGH);
      step+=1;
    } else if (step >= duration / stepDuration) {
      vibrateOnce(direction, endStrength, timeAfter);
    } else step+=1;
  }
}

void setVibrate(String direction, float strength) {
  intensity = map(strength, 1, 100, min_intensity, max_intensity);
  if (intensity > max_intensity) intensity = max_intensity;
  else if (strength == 0) intensity = 0;

  if (direction == "right") {
    analogWrite(vibrPinR, intensity);
  } else if (direction == "left") {
    analogWrite(vibrPinL, intensity);
  } else if (direction == "both") {
    analogWrite(vibrPinR, intensity);
    analogWrite(vibrPinL, intensity);
  }
}

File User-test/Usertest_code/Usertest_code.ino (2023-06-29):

/* June 2023
 * Code by Jochem Verstegen for Final Bachelor Project
 * Eindhoven University of Technology, faculty of Industrial Design
 *
 * This code can be used together with the user test video.
 * The vibration patterns are synchronized with the times they occur in the video.
 * For the electronics needed, see the "Electronics.png" file in the user test folder.
 * Pressing (and holding) the LEFT button will play the vibration patterns with communication phase.
 * The RIGHT button turns off the communication phase.
 */

const int ledPin = 13;
const int vibrPinL = 6;
const int vibrPinR = 5;
const int buttonPinL = 7;
const int buttonPinR = 8;

String side = "none";
int sideNr = 0;

float intensity;
const int max_intensity = 208;
const int min_intensity = 25;

long int time = 0;
long int vibrateTime = 0;
bool vibrating = false;
int step = 0;
int order = 1;
int count = 0;
int randomCount = 0;

bool running = false;
bool communication = true;
long int startTime = 0;

// Here set the times at which each turn is indicated in the video
// also set the amount of communication waves should happen,
// and the side to which the video turns
long int turn1 = 3000;
const String side1 = "left";
const int wave1 = 2;
long int turn2 = 18400;
const String side2 = "right";
const int wave2 = 2;
long int turn3 = 31300;
const String side3 = "left";
const int wave3 = 5;
long int turn4 = 47000;
const String side4 = "left";
const int wave4 = 1;
long int turn5 = 63000;
const String side5 = "left";
const int wave5 = 4;
long int turn6 = 78600;
const String side6 = "right";
const int wave6 = 1;
long int turn7 = 91000;
const String side7 = "both";
const int wave7 = 3;
long int turn8 = 105000;
const String side8 = "right";
const int wave8 = 1;
long int turn9 = 116200;
const String side9 = "left";
const int wave9 = 4;
long int turn10 = 130000;
const String side10 = "left";
const int wave10 = 3;

int stepsDone = 0;

void setup() {
  // put your setup code here, to run once:
  Serial.begin(9600);
  pinMode(vibrPinR, OUTPUT);
  pinMode(vibrPinL, OUTPUT);
  pinMode(ledPin, OUTPUT);
  pinMode(buttonPinL, INPUT);
  pinMode(buttonPinR, INPUT);
}

/* Two (or maybe three) variations for haptic feedback are compared:
1. Received intention & Communication & Confirm turn
2. Received intention & Confirm turn
(3. Confirm turn)
*/

void loop() {
  // put your main code here, to run repeatedly:
  buttonState();
  if (running) {
    if (millis() >= startTime + turn1 && millis() < startTime + turn2) {
      if (stepsDone < 1) {
        side = side1;
        turn(wave1);
      }
    } else if (millis() >= startTime + turn2 && millis() < startTime + turn3) {
      if (stepsDone < 2) {
        side = side2;
        turn(wave2);
      }
    } else if (millis() >= startTime + turn3 && millis() < startTime + turn4) {
      if (stepsDone < 3) {
        side = side3;
        turn(wave3);
      }
    } else if (millis() >= startTime + turn4 && millis() < startTime + turn5) {
      if (stepsDone < 4) {
        side = side4;
        turn(wave4);
      }
    } else if (millis() >= startTime + turn5 && millis() < startTime + turn6) {
      if (stepsDone < 5) {
        side = side5;
        turn(wave5);
      }
    } else if (millis() >= startTime + turn6 && millis() < startTime + turn7) {
      if (stepsDone < 6) {
        side = side6;
        turn(wave6);
      }
    } else if (millis() >= startTime + turn7 && millis() < startTime + turn8) {
      if (stepsDone < 7) {
        side = side7;
        turn(wave7);
      }
    } else if (millis() >= startTime + turn8 && millis() < startTime + turn9) {
      if (stepsDone < 8) {
        side = side8;
        turn(wave8);
      }
    } else if (millis() >= startTime + turn9 && millis() < startTime + turn10) {
      if (stepsDone < 9) {
        side = side9;
        turn(wave9);
      }
    } else if (millis() >= startTime + turn10) {// && millis() < startTime + turn11) {
      if (stepsDone < 10) {
        side = side10;
        turn(wave10);
      }
    }
  } else {
    if (vibrating) setVibrate("both", 0);
    if (order != 1) order = 1;
    if (count != 0) count = 0;
    if (stepsDone != 0) stepsDone = 0;
    startTime = millis();
    // Serial.println("Not running now");
  }
  
}

void turn(int setWaitCount) { // ALWAYS set "setWaitCount" higher than 0!
  // this mode is the regular usage mode, to indicate a turn:
  switch (order) {
    case 1: // Confirmation of user action:
      Serial.print("Step 1 of turn ");
      Serial.println(stepsDone + 1);
      vibrateOnce(side, 70, 100);
      while(vibrating) vibrateOnce(side, 70, 100);
      delay(100);
      vibrateOnce(side, 70, 100);
      while(vibrating) vibrateOnce(side, 70, 100);
      delay(100);
      vibrateOnce(side, 70, 100);
      while(vibrating) vibrateOnce(side, 70, 100);
      order = 2;
      delay(500);
      time = millis();
      break;
    case 2: // Waiting during communication:
      Serial.print("Step 2 of turn ");
      Serial.println(stepsDone + 1);
      if (communication) {
        if (millis() >= time + 300) {               //THEN after 400ms do this:
          vibrateCurve("both", 15, 5, 350, 150);     //gradually go down,
          if(!vibrating) {                            //IF finished vibrating,
            time = millis();                            //set time so it will vibrate up again,
            count++;
            if (count >= setWaitCount) {                //and after a few times, move to next step
              order = 3;
              count = 0;
              delay(200);
            }
          }
        } else {
          vibrateCurve("both", 5, 15, 350, 0);     //FIRST gradually go up.
        }
      } else if (!communication) {
        while (count < setWaitCount) {              // make sure it takes the same amount of time,
          delay(850);                               // without actually vibrating.
          count++;
        }
        order = 3;
        count = 0;
        delay(200);
      }
      break;
    case 3: // Confirm safe to go:
      Serial.print("Step 3 of turn ");
      Serial.println(stepsDone + 1);
      vibrateOnce(side, 60, 200);
      while (vibrating) vibrateOnce(side, 60, 200);
      delay(100);
      vibrateOnce(side, 100, 500);
      while (vibrating) vibrateOnce(side, 100, 500);
      delay(50);
      order = 1;
      stepsDone++;
      delay(50);
      break;
  }
}


void buttonState() {
  int leftButton = digitalRead(buttonPinL);
  int rightButton = digitalRead(buttonPinR);
  if (leftButton == HIGH && rightButton == LOW) {
    communication = true;
    if (!running) {
      startTime = millis();
      time = millis();
      running = true;
    }
  } else if (leftButton == LOW && rightButton == HIGH) {
    communication = false;
    if (!running) {
      startTime = millis();
      time = millis();
      running = true;
    }
  } else running = false;
}
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

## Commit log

2023-06-16 Added files to repo
    Files added:
    - Final report
    - CAD Model (sdworks and stl files)
    - Arduino code
    - Usertest files (Arduino code and results, video coming later)
    - Questionnaire files (questionnaire and results)
    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
    [Usertest results.xlsx, responses to survey.xlsx]
2023-06-16 Added files to repo
    [Complete slidable handle.SLDASM, Inner part inside.SLDPRT, Inner part middle.SLDPRT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]
2023-06-16 Moved arduino code to demoday folder
